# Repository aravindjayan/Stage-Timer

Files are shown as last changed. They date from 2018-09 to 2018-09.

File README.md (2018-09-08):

# Stage-Timer
A custom stage timer made for TEDx FISAT. Uses 2.3" Seven segment displays to indicate time.

A PCB was designed only for the seven segment displays consisting of ULN2003 as the digit driver and BD140 transistor as digit drivers.
The display was driven with an Arduino Pro Mini.

The timer was programmed in Arduino and the following libraries were used.
* [Countimer](https://github.com/inflop/Countimer) by inflop
* [SevenSeg](https://github.com/sigvaldm/SevenSeg) by sigvaldm

Illustrator design is included for a Laser-Cut housing in 3mm acrylic.

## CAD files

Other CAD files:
Hardware/Housing/case.dwg

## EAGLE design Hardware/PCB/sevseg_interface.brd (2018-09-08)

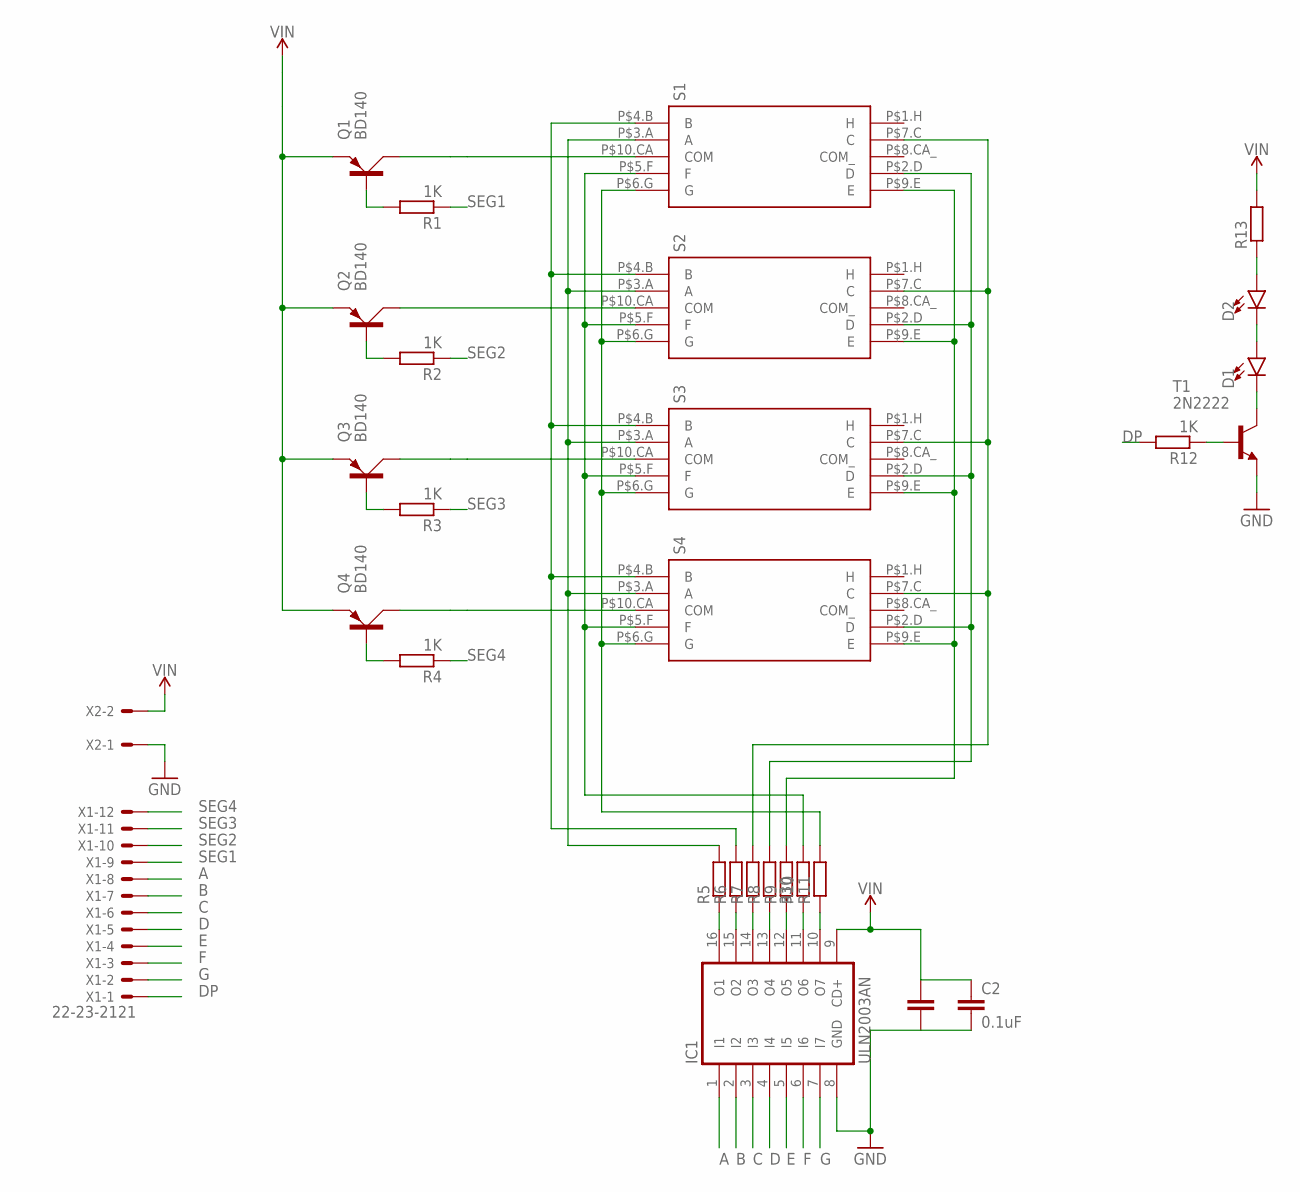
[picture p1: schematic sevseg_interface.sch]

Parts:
C2: 0.1uF; CAP-PTH-SMALL-KIT
D1, D2: LED5MM; LED_5MM
IC1: ULN2003AN; DIL16
Q1, Q2, Q3, Q4: BD140; TO126AV
R1, R2, R3, R4, R12: 1K; 0204/7
R5, R6, R7, R9, R10, R11, R13: R-EU_0204/7; 0204/7
R8: 330; 0204/7
S1, S2, S3, S4: 7SEG_2.3IN_70MM_CA; 2.3INCH_70MM
T1: 2N2222; TO18
X1: 22-23-2121
X2: KK-156-2

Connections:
A: IC1.1 (I1), X1.8
B: IC1.2 (I2), X1.7
C: IC1.3 (I3), X1.6
D: IC1.4 (I4), X1.5
DP: R12.2, X1.1
E: IC1.5 (I5), X1.4
F: IC1.6 (I6), X1.3
G: IC1.7 (I7), X1.2
GND: C2.2, IC1.8 (GND), T1.1 (E), X2.1
unnamed: R6.2, S1.P$4.B (B), S2.P$4.B (B), S3.P$4.B (B), S4.P$4.B (B)
unnamed: R5.2, S1.P$3.A (A), S2.P$3.A (A), S3.P$3.A (A), S4.P$3.A (A)
unnamed: Q1.C, S1.P$10.CA (COM)
unnamed: Q2.C, S2.P$10.CA (COM)
unnamed: Q3.C, S3.P$10.CA (COM)
unnamed: Q4.C, S4.P$10.CA (COM)
unnamed: R10.2, S1.P$5.F (F), S2.P$5.F (F), S3.P$5.F (F), S4.P$5.F (F)
unnamed: R11.2, S1.P$6.G (G), S2.P$6.G (G), S3.P$6.G (G), S4.P$6.G (G)
unnamed: R7.2, S1.P$7.C (C), S2.P$7.C (C), S3.P$7.C (C), S4.P$7.C (C)
unnamed: R8.2, S1.P$2.D (D), S2.P$2.D (D), S3.P$2.D (D), S4.P$2.D (D)
unnamed: R9.2, S1.P$9.E (E), S2.P$9.E (E), S3.P$9.E (E), S4.P$9.E (E)
unnamed: R12.1, T1.2 (B)
unnamed: Q2.B, R2.2
unnamed: Q3.B, R3.2
unnamed: Q4.B, R4.2
unnamed: Q1.B, R1.2
unnamed: IC1.16 (O1), R5.1
unnamed: IC1.15 (O2), R6.1
unnamed: IC1.14 (O3), R7.1
unnamed: IC1.13 (O4), R8.1
unnamed: IC1.12 (O5), R9.1
unnamed: IC1.11 (O6), R10.1
unnamed: IC1.10 (O7), R11.1
unnamed: D1.K (C), T1.3 (C)
unnamed: D1.A, D2.K (C)
unnamed: D2.A, R13.1
SEG1: R1.1, X1.9
SEG2: R2.1, X1.10
SEG3: R3.1, X1.11
SEG4: R4.1, X1.12
VIN: C2.1, IC1.9 (CD+), Q1.E, Q2.E, Q3.E, Q4.E, R13.2, X2.2

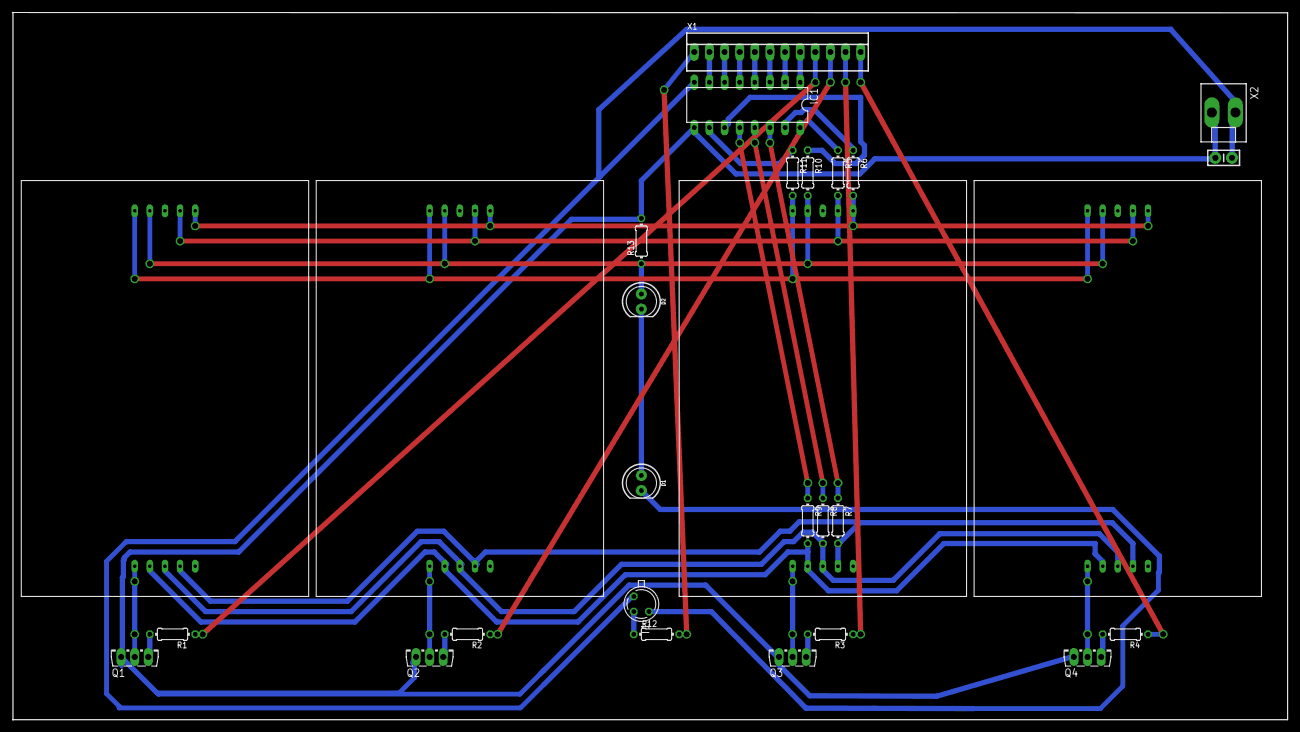
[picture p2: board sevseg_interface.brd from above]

Board: 2 copper layers, 214.2 x 118.8 mm, 28 parts (0 on the bottom side), 40 nets.

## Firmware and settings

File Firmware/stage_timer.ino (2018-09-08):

#include "Countimer.h"
#include <SevenSeg.h>

Countimer timer;
SevenSeg disp(2,3,4,5,6,7,8);

const int numOfDigits=4;
int digitPins[numOfDigits]={10,12,A0,A2};

String m,s;
int mi,se;
long int mis;


void setup() {
  pinMode(9,OUTPUT);
  digitalWrite(9,HIGH);
    disp.setDigitPins(numOfDigits, digitPins);
  //disp.setRefreshRate(150);
  //disp.setDigitDelay(10000000);
  disp.setActivePinState(HIGH,HIGH);
  //disp.setDPPin(9);


  timer.setCounter(0, 18, 00, timer.COUNT_DOWN, onComplete);

    // Print current time every 1s on serial port by calling method refreshClock().
  timer.setInterval(refreshClock, 1000);
}
void refreshClock() {

//  disp.writeClock(timer.getCurrentMinutes(),timer.getCurrentSeconds());
  
}

void onComplete() {
  Serial.println("Complete!!!");
  while(1)
  {

   for(int i=0;i<100;i++)
     disp.write("0000");
   for(int i=0;i<100;i++)
     disp.write("----");

  }
}

void loop() {
  // Run timer
  
  timer.run();
  disp.writeClock(timer.getCurrentMinutes(),timer.getCurrentSeconds());
  
    // Now timer is running and listening for actions.
    // If you want to start the timer, you have to call start() method.
    if(!timer.isCounterCompleted()) {
      timer.start();
    }
   
}

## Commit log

2018-09-08 Initial Commit
    Added detailedREADME.
    [sevseg_interface.brd, sevseg_interface.sch]
2018-09-09 Added AutoCAD compatible dwg format file
    [case.dwg]

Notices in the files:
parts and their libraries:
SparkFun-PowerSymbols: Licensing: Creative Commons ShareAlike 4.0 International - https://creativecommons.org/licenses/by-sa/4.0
